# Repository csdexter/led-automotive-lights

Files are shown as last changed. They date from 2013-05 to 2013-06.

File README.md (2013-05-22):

#LED replacements for automotive light fixtures#

(C) 2013 Radu - Eosif Mihailescu <radu.mihailescu@linux360.ro>

All files in this repository are licensed under the
**GNU Generic Public License v3**, a copy of whose text can be accessed
 [here](http://www.gnu.org/licenses/gpl.html).

This repository contains [EDA](http://en.wikipedia.org/wiki/Electronic_design_automation) source files and associated software sources/configuration data for various LED-based replacements for common automotive light fixtures. The EDA files are in CadSoft Eagle 6 format. Only the `.SCH` (schematic) and `.BRD` (board) files are provided as all data needed for manufacturing can easily be derived from the former. No guarantee is made as to which minor version of Eagle was used to save the file, but it *may* be the latest at the time of this writing.

The board description files *may* contain routing information or be supplied unrouted. In the former case, the routing artwork *may* have been generated by either Eagle's internal autorouter or [FreeRouting](http://www.freerouting.net/).

All files included here are compatible with the free version of Eagle (i.e. describe PCBs having no more than 2 layers and measuring no more than 10cm by 8cm each).

Git tags will be used to mark specific revisions that were actually manufactured so that a correspondence between the evolution of the sources and the status of physical by-products can be maintained.

##WARNING##
*Unless and until explictily noted otherwise, the engineering materials here are laboratory quality and neither intended for manufacturing in production quantities nor for distribution (e.g. as kits) to end-users. The design data here does not explicitly follow any widely-accepted safety/security/EMI regulation or standard, therefore any manufacturing and/or usage in connection with live equipment is entirely at your own risk. Furthermore, the products described by the engineering materials here have not been subjected to any kind of type approval, including for use on a motor vehicle operating on public roads.*

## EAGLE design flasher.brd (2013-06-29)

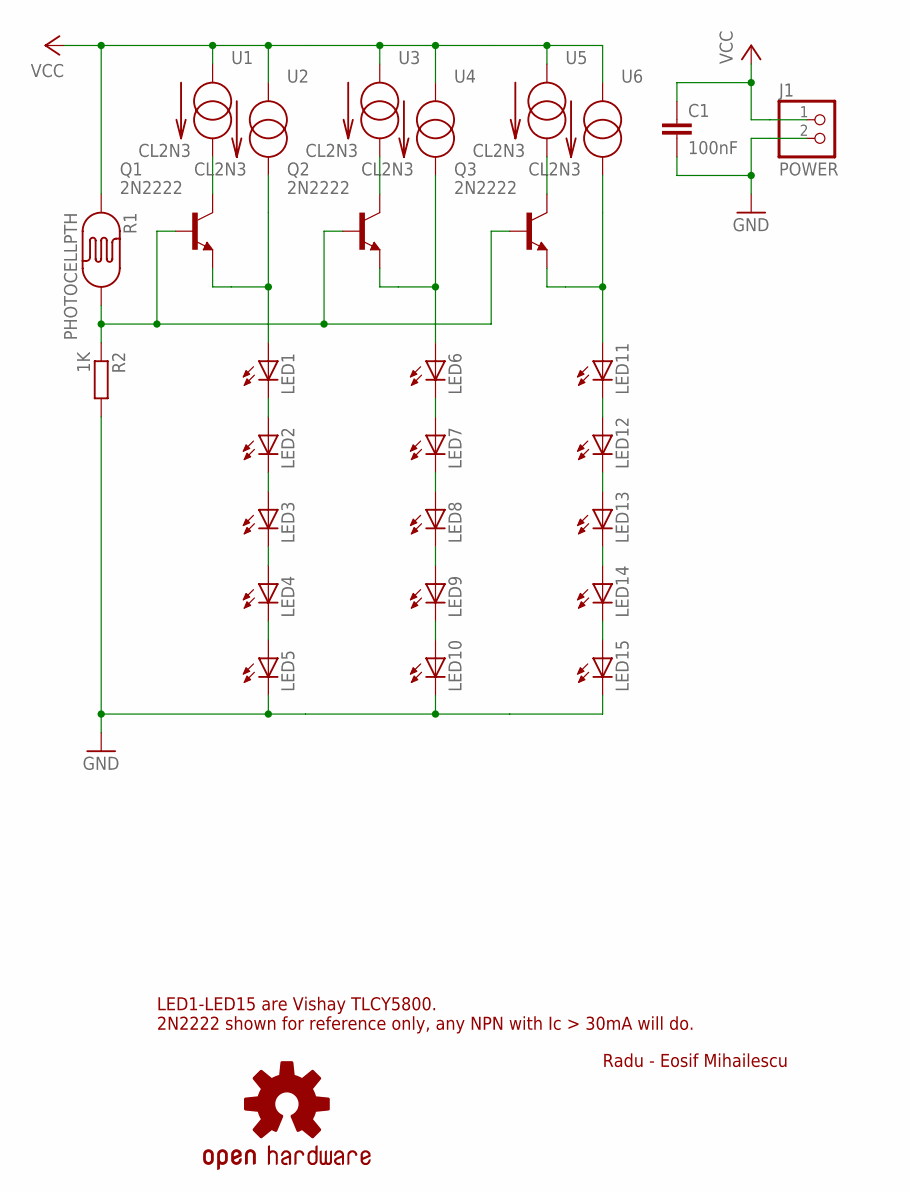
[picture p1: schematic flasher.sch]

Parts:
C1: 100nF; C050-025X075
J1: POWER; 1X02/90
LED1, LED2, LED3, LED4, LED5, LED6, LED7, LED8, LED9, LED10, LED11, LED12, LED13, LED14, LED15: LED5MM
LOGO1: OSHW-LOGOL; OSHW-LOGO-L
Q1, Q2, Q3: 2N2222; TO92-EBC
R1: PHOTOCELLPTH; PHOTOCELL
R2: 1K; 0204/7
U1, U2, U3, U4, U5, U6: CL2N3; TO-92

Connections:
GND: C1.2, J1.2, LED5.K (C), LED10.K (C), LED15.K (C), R2.2
unnamed: LED1.K (C), LED2.A
unnamed: LED2.K (C), LED3.A
unnamed: LED3.K (C), LED4.A
unnamed: LED1.A, Q1.E, U2.3 (OUT)
unnamed: LED4.K (C), LED5.A
unnamed: Q1.C, U1.3 (OUT)
unnamed: Q2.C, U3.3 (OUT)
unnamed: LED6.K (C), LED7.A
unnamed: LED7.K (C), LED8.A
unnamed: LED8.K (C), LED9.A
unnamed: LED6.A, Q2.E, U4.3 (OUT)
unnamed: LED9.K (C), LED10.A
unnamed: Q3.C, U5.3 (OUT)
unnamed: LED11.K (C), LED12.A
unnamed: LED12.K (C), LED13.A
unnamed: LED13.K (C), LED14.A
unnamed: LED11.A, Q3.E, U6.3 (OUT)
unnamed: LED14.K (C), LED15.A
SENSE: Q1.B, Q2.B, Q3.B, R1.2, R2.1
VCC: C1.1, J1.1, R1.1, U1.1 (IN), U2.1 (IN), U3.1 (IN), U4.1 (IN), U5.1 (IN), U6.1 (IN)

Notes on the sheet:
Radu - Eosif Mihailescu
LED1-LED15 are Vishay TLCY5800. 2N2222 shown for reference only, any NPN with Ic > 30mA will do.

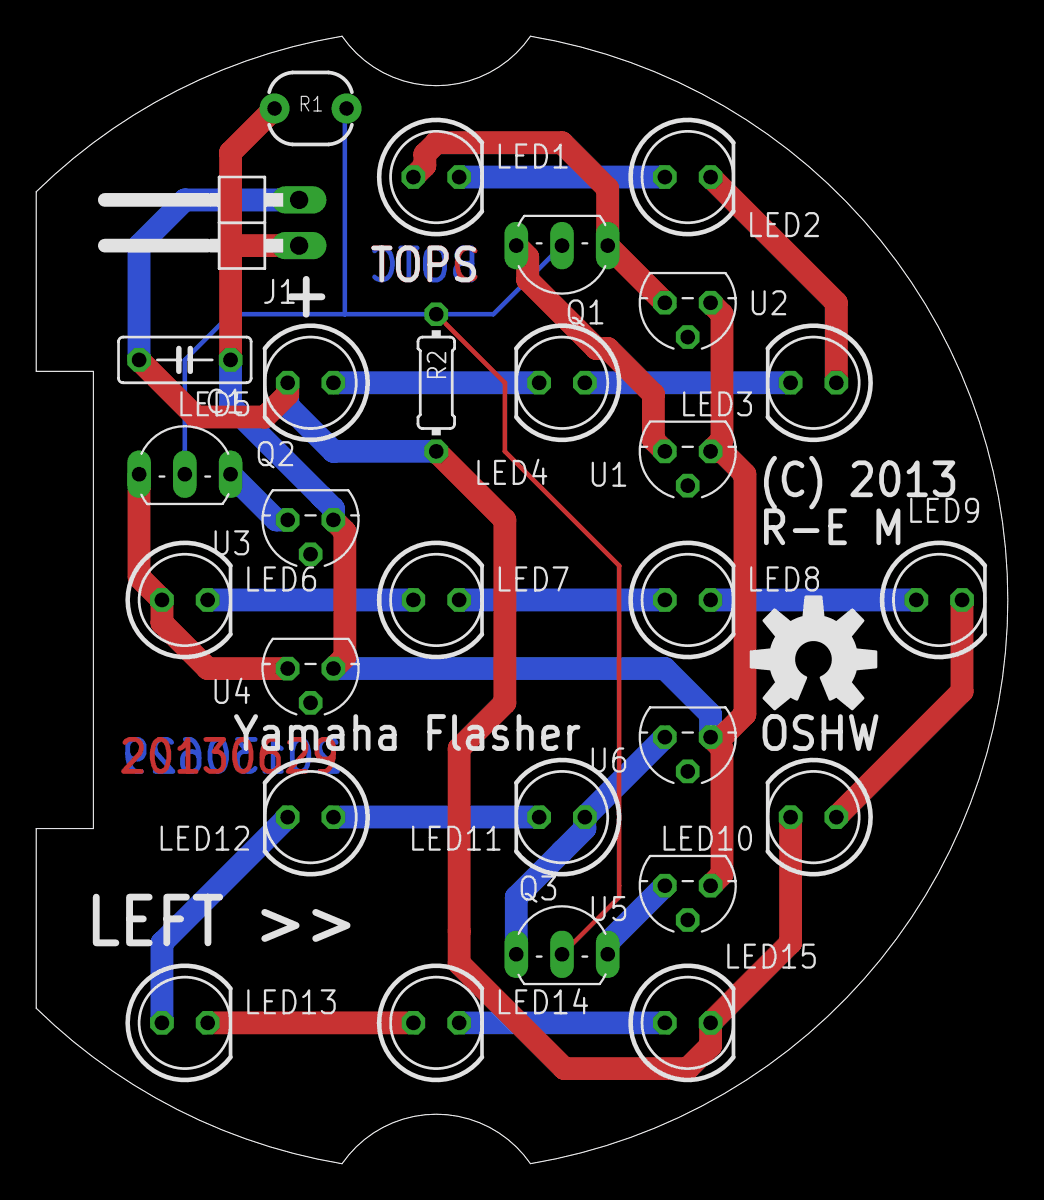
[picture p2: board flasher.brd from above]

Board: 2 copper layers, 54.0 x 62.6 mm, 29 parts (0 on the bottom side), 21 nets.

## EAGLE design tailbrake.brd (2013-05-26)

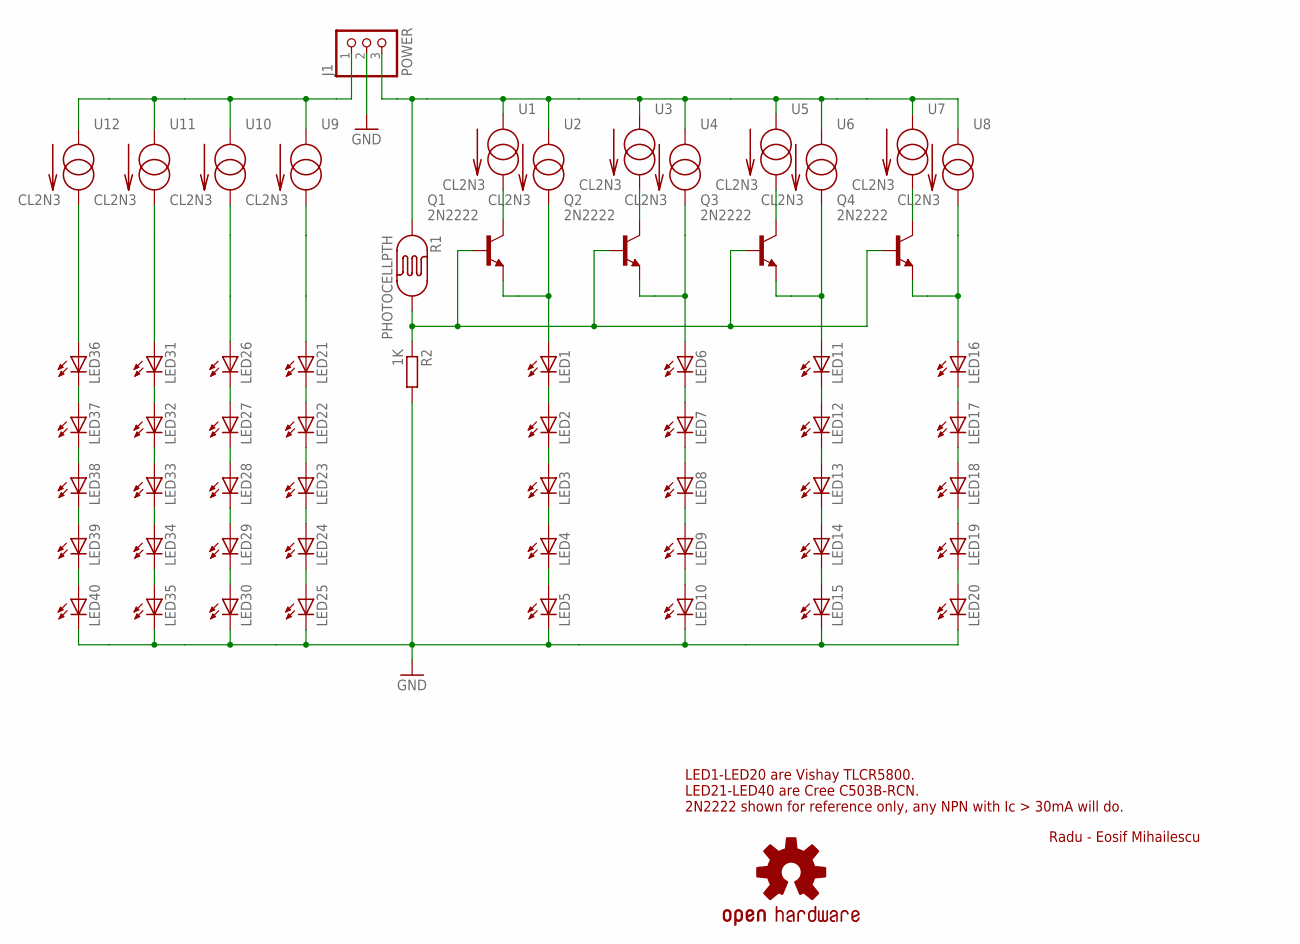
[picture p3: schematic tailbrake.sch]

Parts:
J1: POWER; 1X03/90
LED1, LED2, LED3, LED4, LED5, LED6, LED7, LED8, LED9, LED10, LED11, LED12, LED13, LED14, LED15, LED16, LED17, LED18, LED19, LED20, LED21, LED22, LED23, LED24, LED25, LED26, LED27, LED28, LED29, LED30, LED31, LED32, LED33, LED34, LED35, LED36, LED37, LED38, LED39, LED40: LED5MM
LOGO1: OSHW-LOGOL; OSHW-LOGO-L
Q1, Q2, Q3, Q4: 2N2222; TO92-EBC
R1: PHOTOCELLPTH; PHOTOCELL
R2: 1K; 0204/7
U1, U2, U3, U4, U5, U6, U7, U8, U9, U10, U11, U12: CL2N3; TO-92

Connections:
BRAKE: J1.3, R1.1, U1.1 (IN), U2.1 (IN), U3.1 (IN), U4.1 (IN), U5.1 (IN), U6.1 (IN), U7.1 (IN), U8.1 (IN)
GND: J1.2, LED5.K (C), LED10.K (C), LED15.K (C), LED20.K (C), LED25.K (C), LED30.K (C), LED35.K (C), LED40.K (C), R2.2
unnamed: LED1.K (C), LED2.A
unnamed: LED2.K (C), LED3.A
unnamed: LED3.K (C), LED4.A
unnamed: LED1.A, Q1.E, U2.3 (OUT)
unnamed: LED4.K (C), LED5.A
unnamed: Q1.C, U1.3 (OUT)
unnamed: Q2.C, U3.3 (OUT)
unnamed: LED6.K (C), LED7.A
unnamed: LED7.K (C), LED8.A
unnamed: LED8.K (C), LED9.A
unnamed: LED6.A, Q2.E, U4.3 (OUT)
unnamed: LED9.K (C), LED10.A
unnamed: Q3.C, U5.3 (OUT)
unnamed: LED11.K (C), LED12.A
unnamed: LED12.K (C), LED13.A
unnamed: LED13.K (C), LED14.A
unnamed: LED11.A, Q3.E, U6.3 (OUT)
unnamed: LED14.K (C), LED15.A
unnamed: LED16.K (C), LED17.A
unnamed: LED17.K (C), LED18.A
unnamed: LED18.K (C), LED19.A
unnamed: LED16.A, Q4.E, U8.3 (OUT)
unnamed: LED19.K (C), LED20.A
unnamed: Q4.C, U7.3 (OUT)
unnamed: LED21.K (C), LED22.A
unnamed: LED22.K (C), LED23.A
unnamed: LED23.K (C), LED24.A
unnamed: LED21.A, U9.3 (OUT)
unnamed: LED24.K (C), LED25.A
unnamed: LED26.K (C), LED27.A
unnamed: LED27.K (C), LED28.A
unnamed: LED28.K (C), LED29.A
unnamed: LED26.A, U10.3 (OUT)
unnamed: LED29.K (C), LED30.A
unnamed: LED31.K (C), LED32.A
unnamed: LED32.K (C), LED33.A
unnamed: LED33.K (C), LED34.A
unnamed: LED31.A, U11.3 (OUT)
unnamed: LED34.K (C), LED35.A
unnamed: LED36.K (C), LED37.A
unnamed: LED37.K (C), LED38.A
unnamed: LED38.K (C), LED39.A
unnamed: LED36.A, U12.3 (OUT)
unnamed: LED39.K (C), LED40.A
SENSE: Q1.B, Q2.B, Q3.B, Q4.B, R1.2, R2.1
TAIL: J1.1, U9.1 (IN), U10.1 (IN), U11.1 (IN), U12.1 (IN)

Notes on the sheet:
Radu - Eosif Mihailescu
LED1-LED20 are Vishay TLCR5800. LED21-LED40 are Cree C503B-RCN. 2N2222 shown for reference only, any NPN with Ic > 30mA will do.

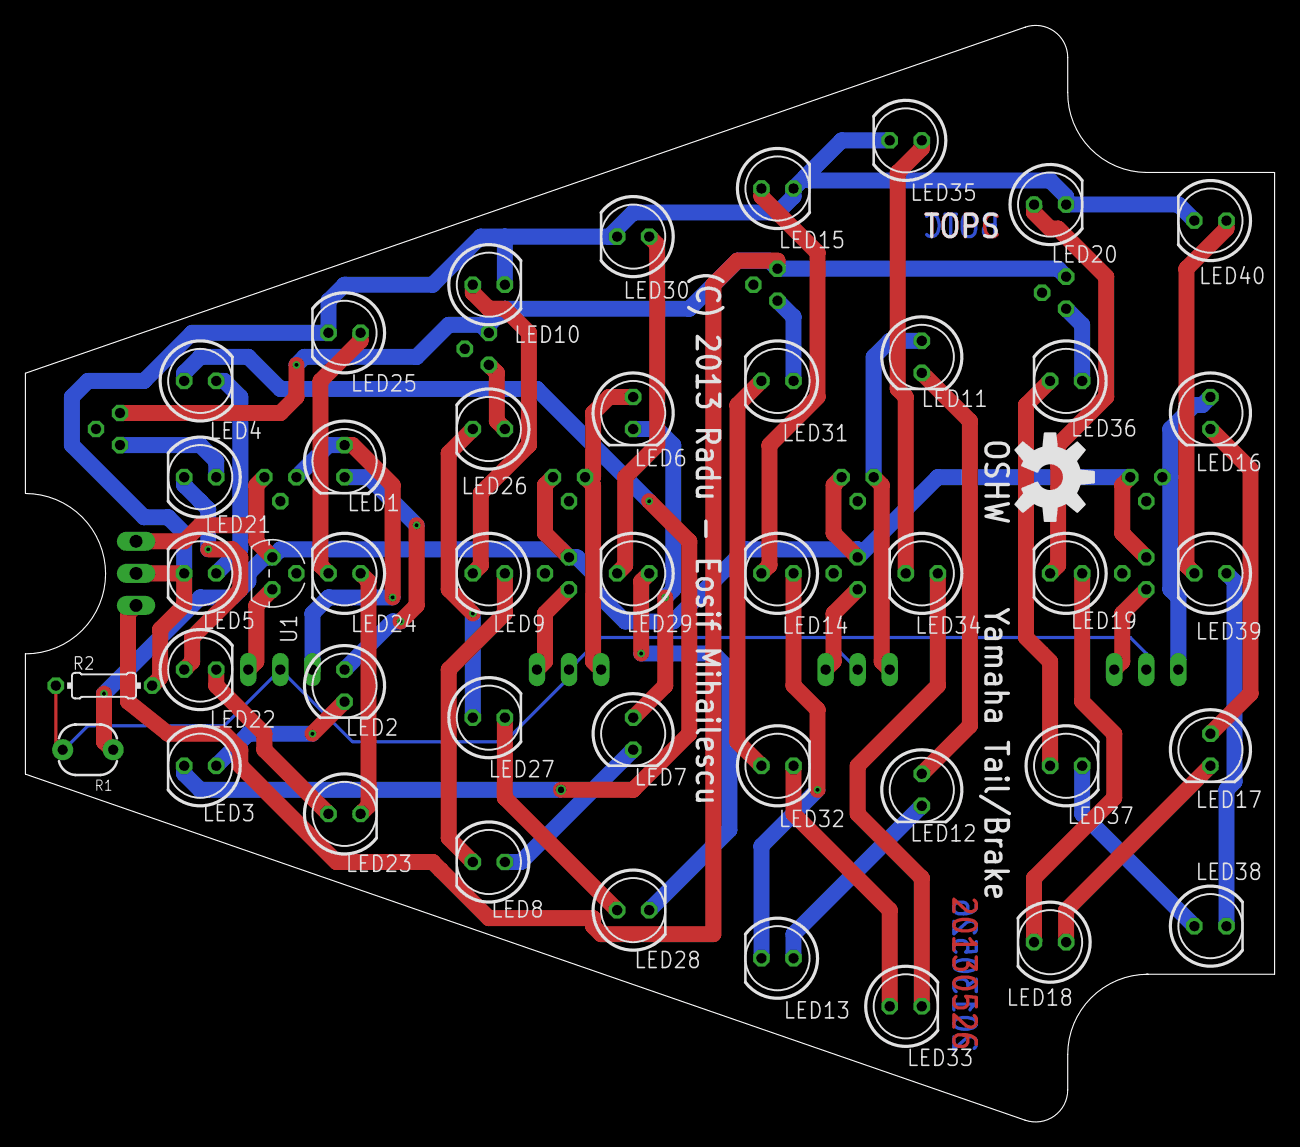
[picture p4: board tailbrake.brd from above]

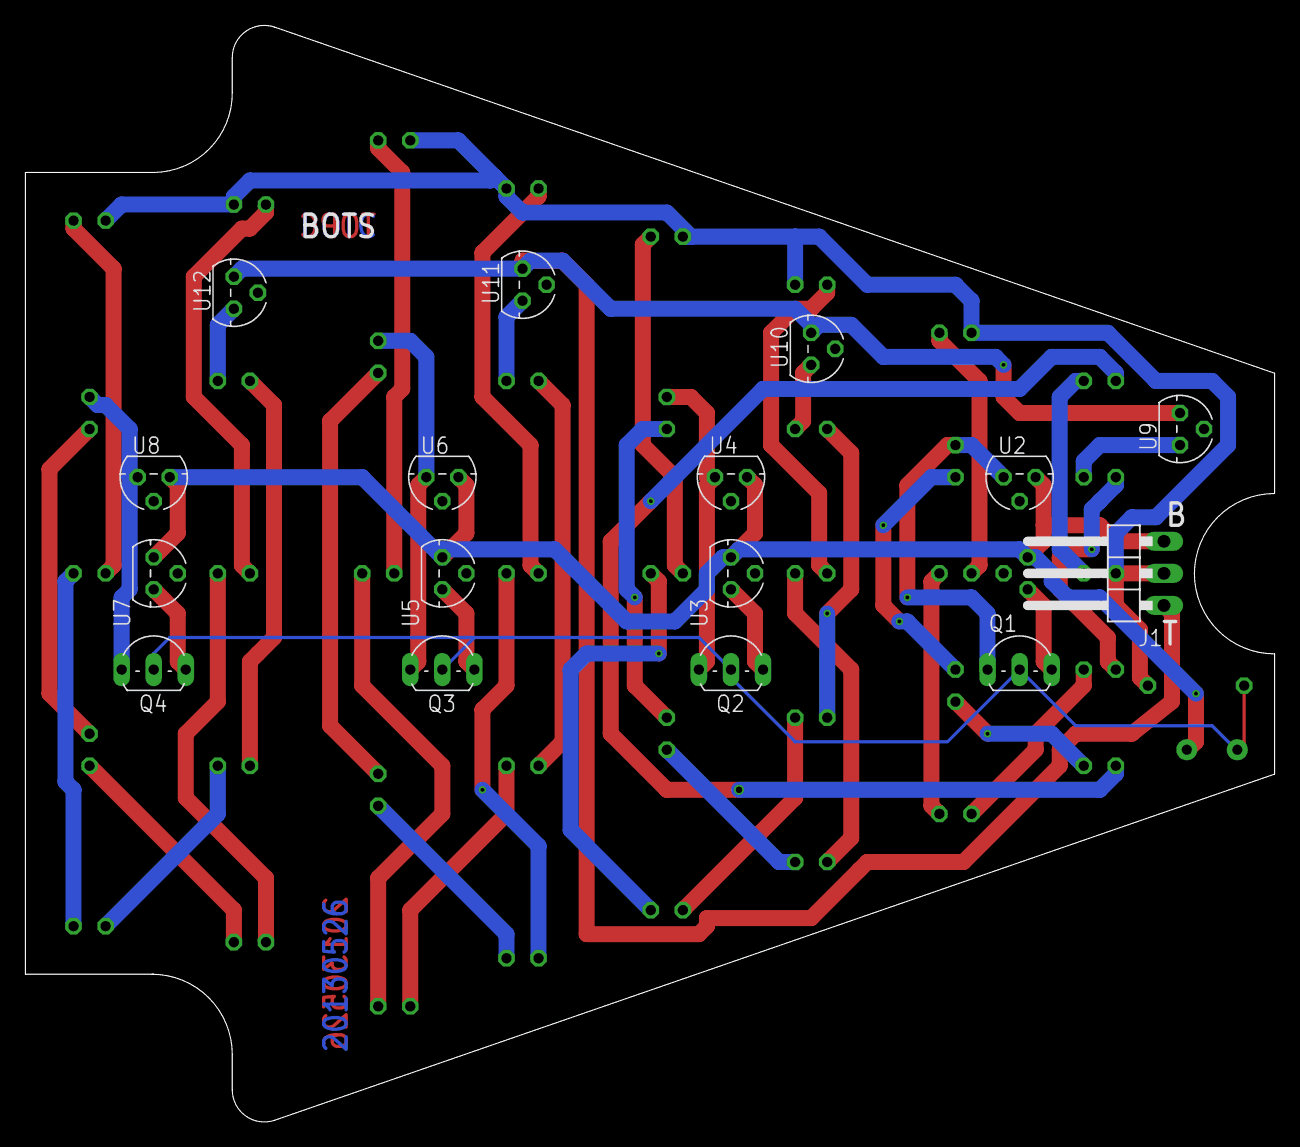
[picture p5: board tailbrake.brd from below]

Board: 2 copper layers, 98.9 x 86.8 mm, 60 parts (16 on the bottom side), 48 nets.

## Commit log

2013-05-22 Initial check-in: - flasher schematic and board for Yamaha cruiser -style flasher/indicator lights - three assembly versions: Simple, Dimmed (less light in darkness) and Pro (MCU-controlled)
    [flasher.brd, flasher.sch]
2013-05-23 Final version, so far - brought flasher to ready for manufacture - done away with Pro assembly variant, not feasible - made design more robust, doing away with power resistor - sorted top silk, added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
    [flasher.brd, flasher.sch]
2013-05-25 Added tail/brake light design: - 20 wide angle LEDs for tail light, 20 narrow angle LEDs for brake light - same dimmer logic as for the flasher - still some fanout to do - still needs constraining to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
    [tailbrake.brd, tailbrake.sch]
2013-05-26 Final version, so far - brought tail/brake to ready for manufacture - two assembly versions: simple and dimmed - sorted top/bottom silk, added branding and extra artwork
    [flasher.brd, tailbrake.brd, tailbrake.sch]
2013-06-29 BUGFIX: - added 0.1uF as recommended by Supertex CL2N3 datasheet - rotated power connector to make it more accessible during assembly
    [flasher.brd, flasher.sch]

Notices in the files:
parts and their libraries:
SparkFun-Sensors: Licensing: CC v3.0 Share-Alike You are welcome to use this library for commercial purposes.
